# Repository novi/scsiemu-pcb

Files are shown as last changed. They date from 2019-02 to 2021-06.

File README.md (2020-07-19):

# Level Converters for SCSI-bus Emulators

This device enables you to convert logic levels between SCSI-bus and Raspberry-Pi GPIOs.

* Combine with Raspberry Pi Zero
* Supports Target(=e.g. Behaves as SCSI hard-disk) mode
* Supports Initiator, Host(=Dump data from SCSI hard-disk etc...) mode 

NOTE: Some features are depends on your SCSI emulation software.

## Compatible SCSI-bus Emulation Software

* [scsiemu](https://github.com/novi/scsiemu) [WIP]
* [akuker/RASCSI](https://github.com/akuker/RASCSI)

## Gerbers and BOM(Parts List)

* Gerber: `scsiemu-gerber/`
* BOM: `scsiemu-bom.csv`

# Related Projects

* [Tiny SCSI Emulator](https://bitbucket.org/tinyscsi/tinyscsiemulator)
* [LC-SCSI](https://github.com/pgodwin/LC-SCSI)
* [SCSI2SD](http://www.codesrc.com/mediawiki/index.php/SCSI2SD)

# License

[Attribution-ShareAlike 4.0 International (CC BY-SA 4.0)](https://creativecommons.org/licenses/by-sa/4.0/)

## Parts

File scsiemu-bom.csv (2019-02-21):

Ref Name | Qty | Component | Value | Package | Part Number | Part Number (Digi-Key) | Part Number 秋月電子 | Description
RN 5,7,8,10 | 4 |  | 220 | Cat16-8 | CAT16-221J8LF | CAT16-221J8LFCT-ND |  | Resistor
RN 6,9,11 | 3 |  | 330 | Cat16-8 | CAT16-331J8LF | CAT16-331J8LFCT-ND |  | Resistor
RN 1,2,3,4 | 4 |  | 10k | Cat16-8 | CAT16-103J8LF | CAT16-103J8LFCT-ND |  | Resistor
C1,2,3,4 | 4 |  | 0.1u JB | 1206 | C1608JB1H104K |  | P-06166 | Capacitor
C5 | 1 |  | 10u JB | 1206 | GRM319B31C106KE15D |  | P-12730 | Capacitor
F1,2 | 2 |  | 1A | 1206 | 0ZCJ0100FF2E | 507-1806-1-ND |  | Fuse
R1 | 1 | Resistor for LED | 1k | 0603 |  |  |  | Resistor
U1,2,3,4 | 4 |  | 74LS641-1 | SOIC | SN74LS641-1DW | 296-34017-5-ND
FL1,2 | 2 |  | 0.22u |  | NFM21PC224R1C3D | 490-6981-1-ND |  | EMI Filter
LED1 | 1 |  |  | 3mm |  |  |  | LED
J3 | (1) | USB Connector |  |  | ZX62R-B-5P |  | C-05254 | Connector
J2 | (1) | SCSI Connector (DSUB) |  |  | 5787082-5 | A31812-ND |  | Connector
J2 | (1) | SCSI Connector |  |  | 10250-5212PL |  |  | Connector
J1 | 1 | Pin Sockets | 40P |  |  |  | C-00085 | Connector
J4 | (1) | Power Connector | 2P | PH | S2B-PH-K |  | C-12633 | Connector
J5 | (1) | I2C Connector | 3P | PH | S3B-PH-K |  |  | Connector

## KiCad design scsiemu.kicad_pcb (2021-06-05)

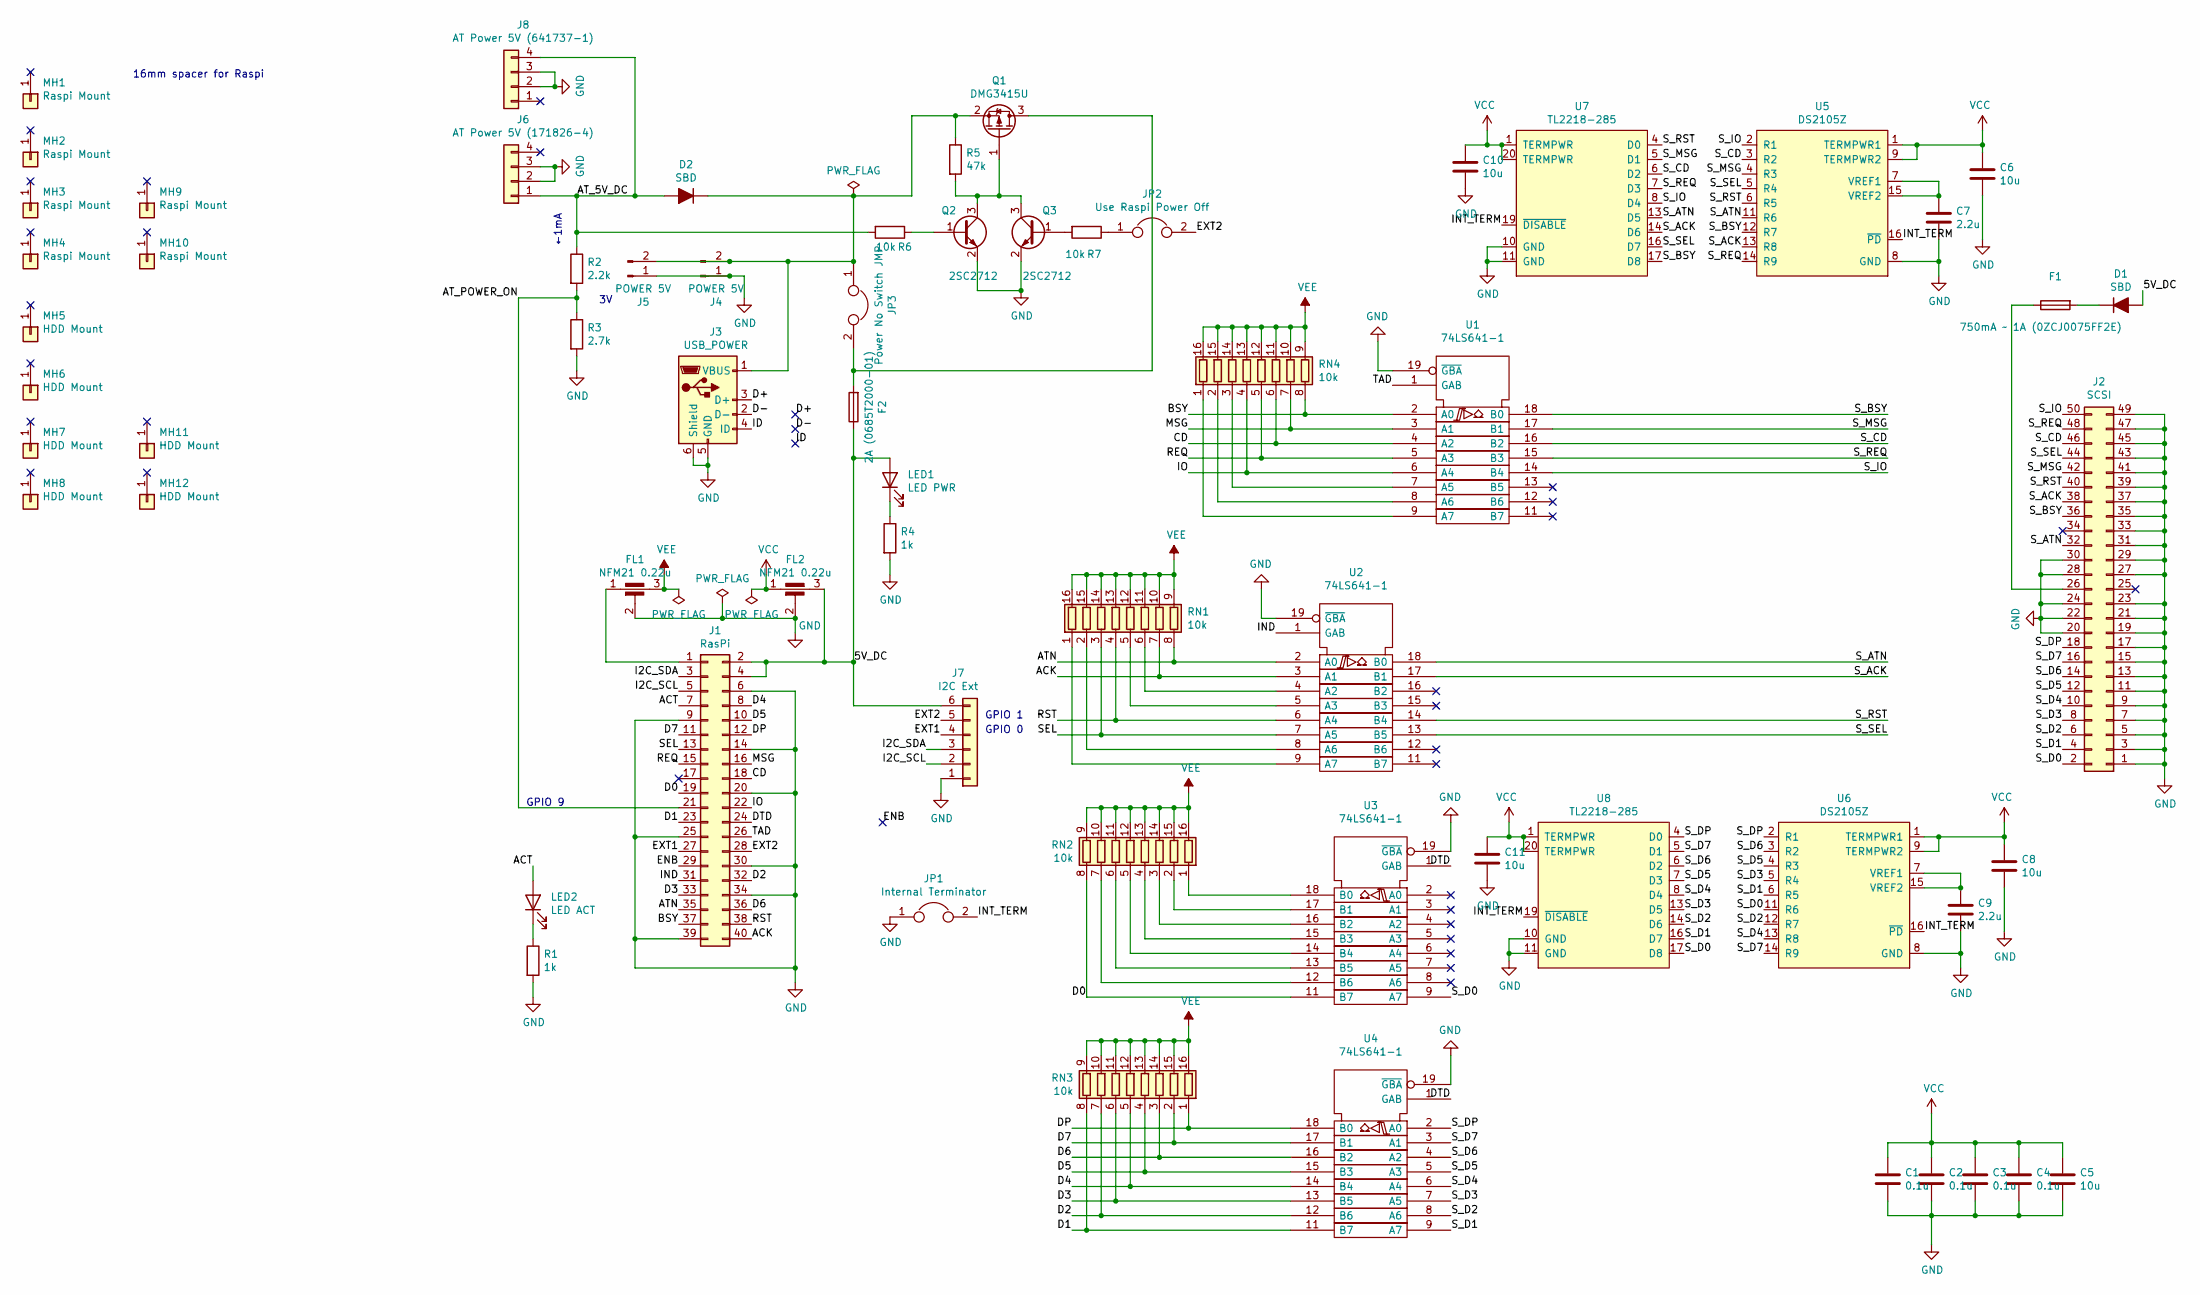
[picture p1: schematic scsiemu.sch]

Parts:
C1, C2, C3, C4: 0.1u; C_0603_1608Metric_Pad1.05x0.95mm_HandSolder
C5, C6, C8, C10, C11: 10u; C_1206_3216Metric_Pad1.42x1.75mm_HandSolder
C7, C9: 2.2u; C_0603_1608Metric_Pad1.05x0.95mm_HandSolder
D1, D2: SBD; D_SOD-123_HandSoldering
F1: 750mA ~~ 1A (0ZCJ0075FF2E); Fuse_1206_3216Metric_Pad1.42x1.75mm_HandSolder
F2: 2A (0685T2000-01); Fuse_1206_3216Metric_Pad1.42x1.75mm_HandSolder
FL1, FL2: NFM21 0.22u; NFM21PC
J1: RasPi; PinSocket_2x20_P2.54mm_Vertical
J2: SCSI; PinHeader_2x25_P2.54mm_Horizontal
J3: USB_POWER; USB_ZX62R-B-5P_HandSoldering
J4, J5: POWER 5V; JST_XH_B2B-XH-A_1x02_P2.50mm_Vertical
J6: AT Power 5V (171826-4); Molex_171826-4
J7: I2C Ext; JST_XH_B6B-XH-A_1x06_P2.50mm_Vertical
J8: AT Power 5V (641737-1); TE_641737-1
JP1: Internal Terminator; PinHeader_1x02_P2.54mm_Vertical
JP2: Use Raspi Power Off; SolderJumper-2_P1.3mm_Open_RoundedPad1.0x1.5mm
JP3: Power No Switch JMP; SolderJumper-2_P1.3mm_Open_RoundedPad1.0x1.5mm
LED1: LED PWR; LED_0603_1608Metric_Pad1.05x0.95mm_HandSolder
LED2: LED ACT; LED_0603_1608Metric_Pad1.05x0.95mm_HandSolder
MH1, MH2, MH3, MH4, MH9, MH10: Raspi Mount; MountingHole_2.2mm_M2
MH5, MH6, MH7, MH8, MH11, MH12: HDD Mount; MountingHole_3.5mm
Q1: DMG3415U; SOT-23_Handsoldering
Q2, Q3: 2SC2712; SOT-23_Handsoldering
R1, R4: 1k; R_0603_1608Metric_Pad1.05x0.95mm_HandSolder
R2: 2.2k; R_0603_1608Metric_Pad1.05x0.95mm_HandSolder
R3: 2.7k; R_0603_1608Metric_Pad1.05x0.95mm_HandSolder
R5: 47k; R_0603_1608Metric_Pad0.98x0.95mm_HandSolder
R6, R7: 10k; R_0603_1608Metric_Pad0.98x0.95mm_HandSolder
RN1, RN2, RN3, RN4: 10k; R_Cat16-8
U1, U2, U3, U4: 74LS641-1; SO-20_12.8x7.5mm_P1.27mm
U5, U6: DS2105Z; SOIC-16_3.9x9.9mm_P1.27mm
U7, U8: TL2218-285; TSSOP-20_4.4x6.5mm_P0.65mm

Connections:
/5V_DC: D1.2 (A), F2.1, FL2.3, J1.2, J1.4, J7.6, LED1.2 (A)
/ACK: J1.40, RN1.7 (R7.1), U2.3 (A1)
/ACT: J1.7, LED2.2 (A)
/ATN: J1.35, RN1.8 (R8.1), U2.2 (A0)
/AT_5V_DC: D2.2 (A), J6.1, J8.4, R2.1, R6.2
/AT_POWER_ON: J1.21, R2.2, R3.1
/BSY: J1.37, RN4.8 (R8.1), U1.2 (A0)
/CD: J1.18, RN4.6 (R6.1), U1.4 (A2)
/D0: J1.19, RN2.8 (R8.1), U3.11 (B7)
/D1: J1.23, RN3.8 (R8.1), U4.11 (B7)
/D2: J1.32, RN3.7 (R7.1), U4.12 (B6)
/D3: J1.33, RN3.6 (R6.1), U4.13 (B5)
/D4: J1.8, RN3.5 (R5.1), U4.14 (B4)
/D5: J1.10, RN3.4 (R4.1), U4.15 (B3)
/D6: J1.36, RN3.3 (R3.1), U4.16 (B2)
/D7: J1.11, RN3.2 (R2.1), U4.17 (B1)
/D+: J3.3 (D+)
/D-: J3.2 (D-)
/DP: J1.12, RN3.1 (R1.1), U4.18 (B0)
/DTD: J1.24, U3.1 (GAB), U4.1 (GAB)
/ENB: J1.29
/EXT1: J1.27, J7.4
/EXT2: J1.28, J7.5, JP2.2
/I2C_SCL: J1.5, J7.2
/I2C_SDA: J1.3, J7.3
/ID: J3.4 (ID)
/IND: J1.31, U2.1 (GAB)
/INT_TERM: JP1.2, U5.16 (~PD), U6.16 (~PD), U7.19 (~DISABLE), U8.19 (~DISABLE)
/IO: J1.22, RN4.4 (R4.1), U1.6 (A4)
/MSG: J1.16, RN4.7 (R7.1), U1.3 (A1)
/REQ: J1.15, RN4.5 (R5.1), U1.5 (A3)
/RST: J1.38, RN1.4 (R4.1), U2.6 (A4)
/SEL: J1.13, RN1.3 (R3.1), U2.7 (A5)
/S_ACK: J2.38, U2.17 (B1), U5.13 (R8), U7.14 (D6)
/S_ATN: J2.32, U2.18 (B0), U5.11 (R6), U7.13 (D5)
/S_BSY: J2.36, U1.18 (B0), U5.12 (R7), U7.17 (D8)
/S_CD: J2.46, U1.16 (B2), U5.3 (R2), U7.6 (D2)
/S_D0: J2.2, U3.9 (A7), U6.11 (R6), U8.17 (D8)
/S_D1: J2.4, U4.9 (A7), U6.6 (R5), U8.16 (D7)
/S_D2: J2.6, U4.8 (A6), U6.12 (R7), U8.14 (D6)
/S_D3: J2.8, U4.7 (A5), U6.5 (R4), U8.13 (D5)
/S_D4: J2.10, U4.6 (A4), U6.13 (R8), U8.8 (D4)
/S_D5: J2.12, U4.5 (A3), U6.4 (R3), U8.7 (D3)
/S_D6: J2.14, U4.4 (A2), U6.3 (R2), U8.6 (D2)
/S_D7: J2.16, U4.3 (A1), U6.14 (R9), U8.5 (D1)
/S_DP: J2.18, U4.2 (A0), U6.2 (R1), U8.4 (D0)
/S_IO: J2.50, U1.14 (B4), U5.2 (R1), U7.8 (D4)
/S_MSG: J2.42, U1.17 (B1), U5.4 (R3), U7.5 (D1)
/S_REQ: J2.48, U1.15 (B3), U5.14 (R9), U7.7 (D3)
/S_RST: J2.40, U2.14 (B4), U5.6 (R5), U7.4 (D0)
/S_SEL: J2.44, U2.13 (B5), U5.5 (R4), U7.16 (D7)
/TAD: J1.26, U1.1 (GAB)
GND: C1.2, C2.2, C3.2, C4.2, C5.2, C6.2, C7.2, C8.2, C9.2, C10.2, C11.2, FL1.2, FL2.2, J1.6, J1.9, J1.14, J1.20, J1.25, J1.30, J1.34, J1.39, J2.1, J2.3, J2.5, J2.7, J2.9, J2.11, J2.13, J2.15, J2.17, J2.19, J2.20, J2.21, J2.22, J2.23, J2.24, J2.27, J2.28, J2.29, J2.30, J2.31, J2.33, J2.35, J2.37, J2.39, J2.41, J2.43, J2.45, J2.47, J2.49, J3.5 (GND), J3.6 (Shield), J4.1, J5.1, J6.2, J6.3, J7.1, J8.2, J8.3, JP1.1, Q2.2 (E), Q3.2 (E), R1.2, R3.2, R4.2, U1.10 (GND), U1.19 (~GBA), U2.10 (GND), U2.19 (~GBA), U3.10 (GND), U3.19 (~GBA), U4.10 (GND), U4.19 (~GBA), U5.8 (GND), U6.8 (GND), U7.10 (GND), U7.11 (GND), U8.10 (GND), U8.11 (GND)
unnamed: C7.1, U5.7 (VREF1), U5.15 (VREF2)
unnamed: C9.1, U6.7 (VREF1), U6.15 (VREF2)
unnamed: D1.1 (K), F1.2
unnamed: D2.1 (K), J3.1 (VBUS), J4.2, J5.2, JP3.1, Q1.2 (S), R5.1
unnamed: F1.1, J2.26
unnamed: F2.2, JP3.2, Q1.3 (D)
unnamed: FL1.1, J1.1
unnamed: JP2.1, R7.1
unnamed: LED1.1 (K), R4.1
unnamed: LED2.1 (K), R1.1
unnamed: Q1.1 (G), Q2.3 (C), Q3.3 (C), R5.2
unnamed: Q2.1 (B), R6.1
unnamed: Q3.1 (B), R7.2
unnamed: RN1.1 (R1.1), U2.9 (A7)
unnamed: RN1.2 (R2.1), U2.8 (A6)
unnamed: RN1.5 (R5.1), U2.5 (A3)
unnamed: RN1.6 (R6.1), U2.4 (A2)
unnamed: RN2.1 (R1.1), U3.18 (B0)
unnamed: RN2.2 (R2.1), U3.17 (B1)
unnamed: RN2.3 (R3.1), U3.16 (B2)
unnamed: RN2.4 (R4.1), U3.15 (B3)
unnamed: RN2.5 (R5.1), U3.14 (B4)
unnamed: RN2.6 (R6.1), U3.13 (B5)
unnamed: RN2.7 (R7.1), U3.12 (B6)
unnamed: RN4.1 (R1.1), U1.9 (A7)
unnamed: RN4.2 (R2.1), U1.8 (A6)
unnamed: RN4.3 (R3.1), U1.7 (A5)
VCC: C1.1, C2.1, C3.1, C4.1, C5.1, C6.1, C8.1, C10.1, C11.1, FL2.1, U1.20 (VCC), U2.20 (VCC), U3.20 (VCC), U4.20 (VCC), U5.1 (TERMPWR1), U5.9 (TERMPWR2), U6.1 (TERMPWR1), U6.9 (TERMPWR2), U7.1 (TERMPWR), U7.20 (TERMPWR), U8.1 (TERMPWR), U8.20 (TERMPWR)
VEE: FL1.3, RN1.9 (R8.2), RN1.10 (R7.2), RN1.11 (R6.2), RN1.12 (R5.2), RN1.13 (R4.2), RN1.14 (R3.2), RN1.15 (R2.2), RN1.16 (R1.2), RN2.9 (R8.2), RN2.10 (R7.2), RN2.11 (R6.2), RN2.12 (R5.2), RN2.13 (R4.2), RN2.14 (R3.2), RN2.15 (R2.2), RN2.16 (R1.2), RN3.9 (R8.2), RN3.10 (R7.2), RN3.11 (R6.2), RN3.12 (R5.2), RN3.13 (R4.2), RN3.14 (R3.2), RN3.15 (R2.2), RN3.16 (R1.2), RN4.9 (R8.2), RN4.10 (R7.2), RN4.11 (R6.2), RN4.12 (R5.2), RN4.13 (R4.2), RN4.14 (R3.2), RN4.15 (R2.2), RN4.16 (R1.2)

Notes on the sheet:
←1mA
GPIO 0
GPIO 1
16mm spacer for Raspi
GPIO 9

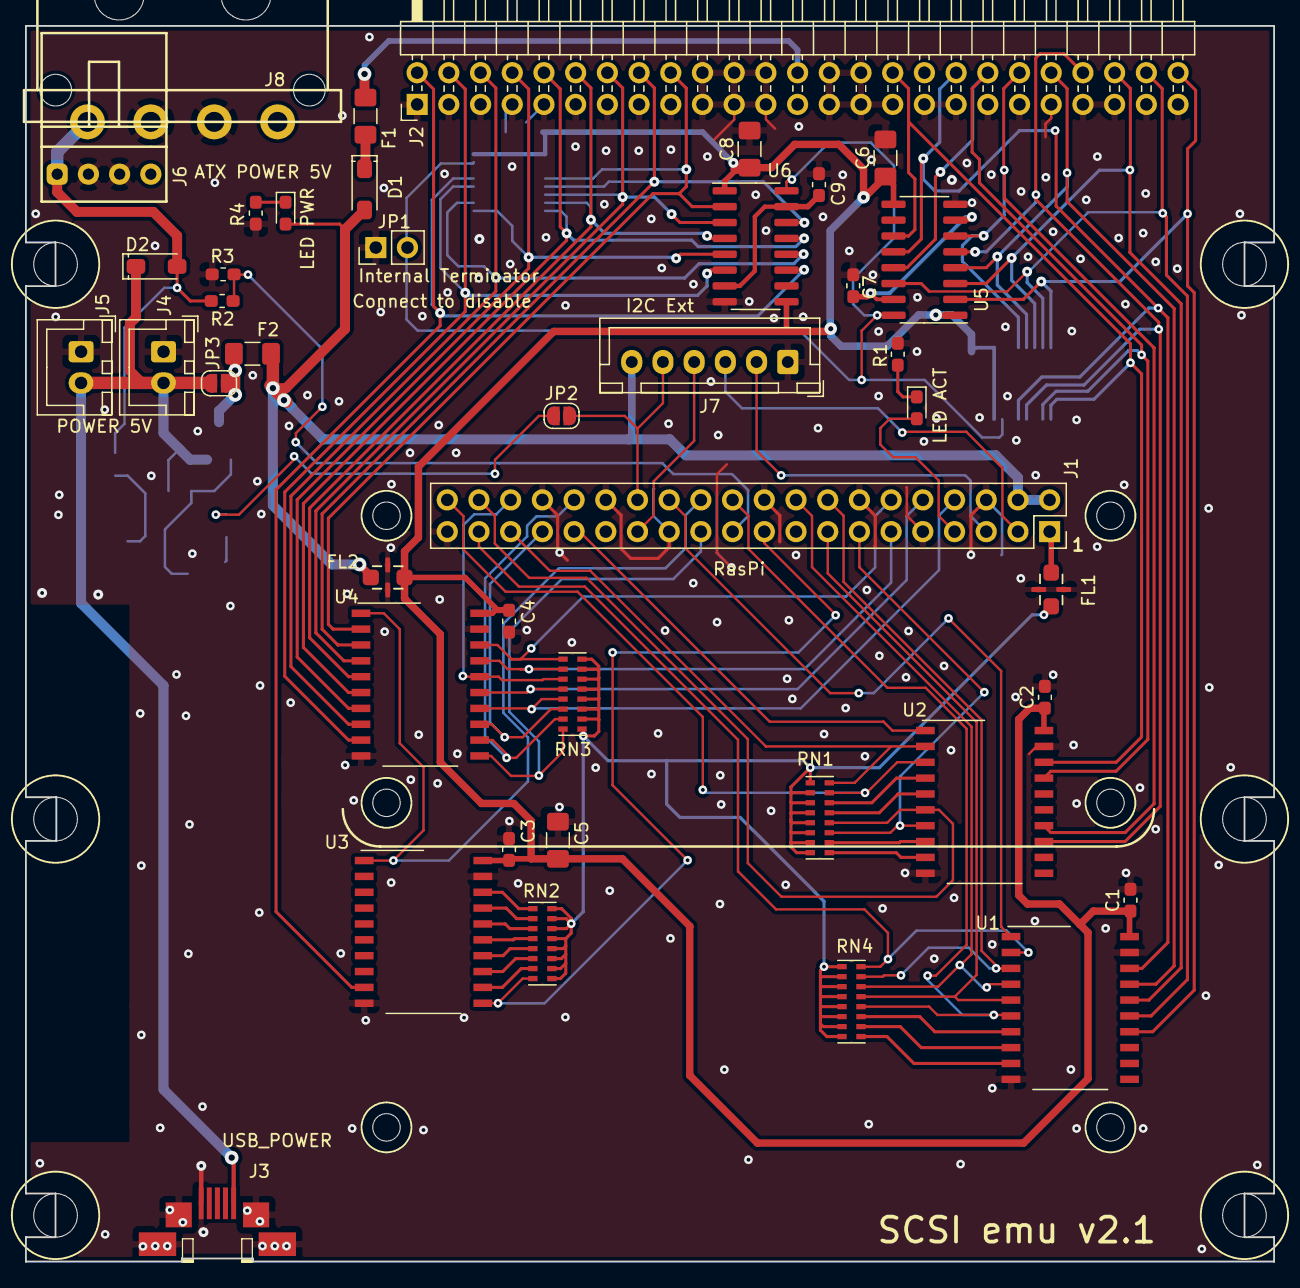
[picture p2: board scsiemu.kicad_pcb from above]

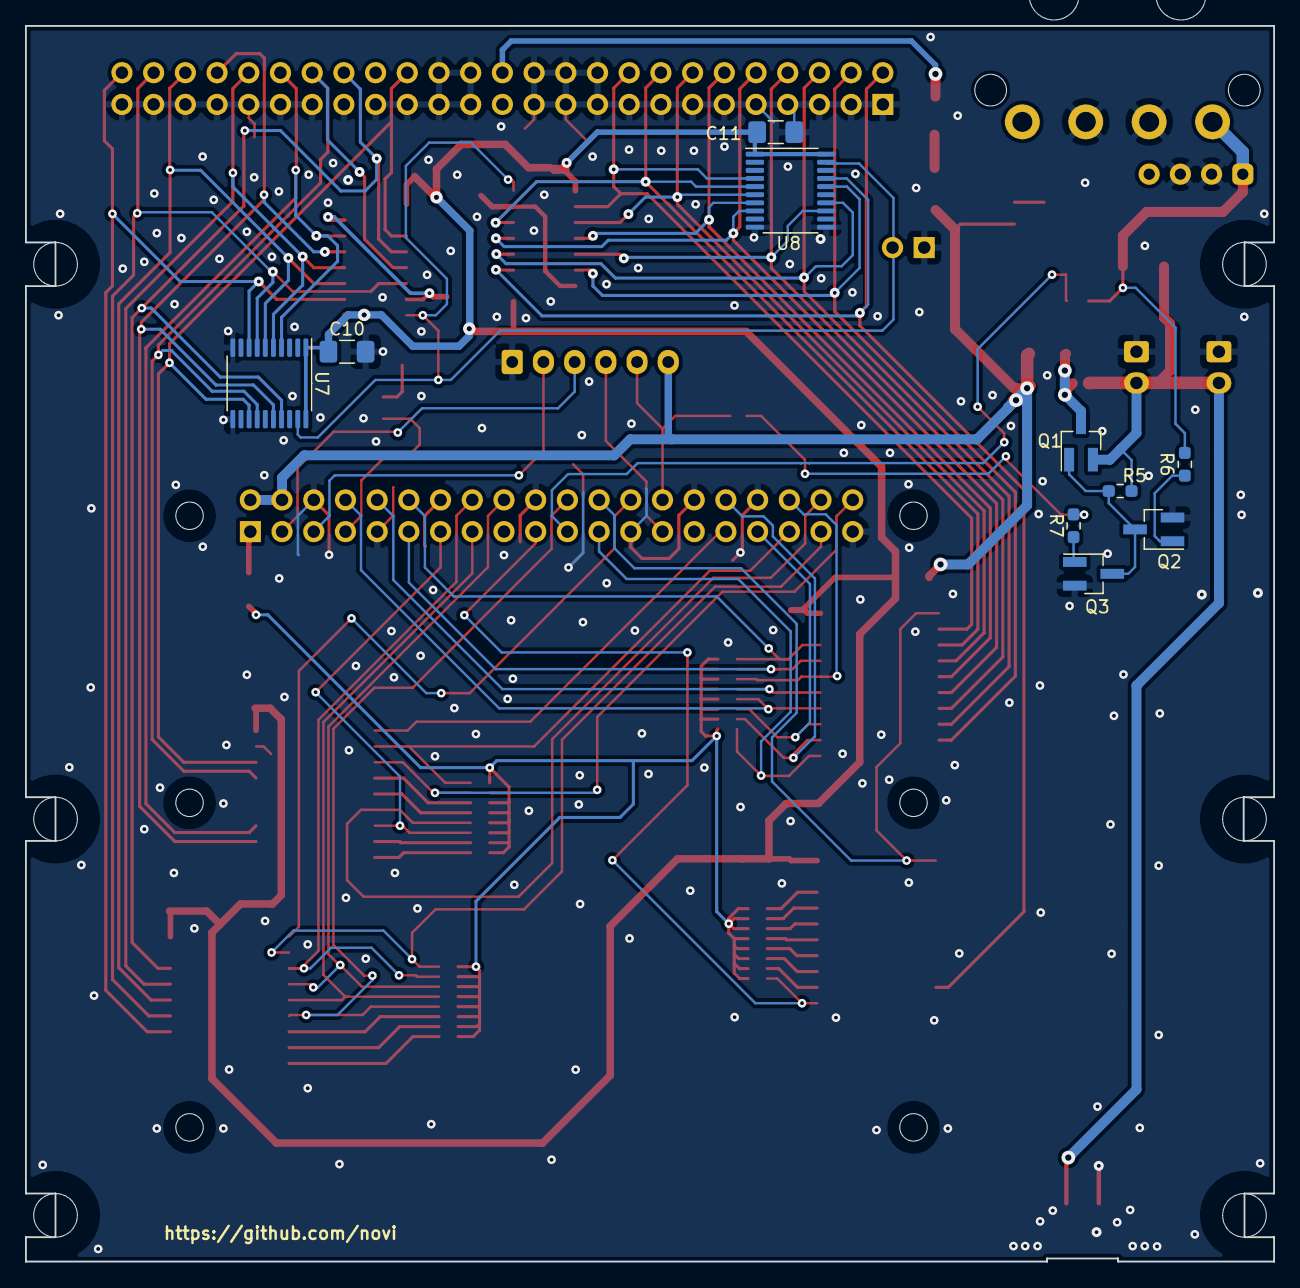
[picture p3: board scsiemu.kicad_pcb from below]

Board: 2 copper layers, 100.0 x 99.0 mm, 64 parts (10 on the bottom side), 78 nets.

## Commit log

2019-02-21 add KiCad projects
    [scsiemu-bom.csv, scsiemu.kicad_pcb, scsiemu.sch]
2020-05-16 add gerber files
    [scsiemu-B_Cu.gbl, scsiemu-B_Mask.gbs, scsiemu-B_Paste.gbp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]
2020-09-13 Internal 50pin version (#1)
    [scsiemu-B_Cu.gbl, scsiemu-B_Mask.gbs, scsiemu-B_Paste.gbp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]
2020-09-26 termination on/off jumper fix GND plane
    [scsiemu.kicad_pcb, scsiemu.sch]
2021-04-17 minor update
    [scsiemu.kicad_pcb, scsiemu.sch]
2021-04-18 add auto power off
    [scsiemu.kicad_pcb, scsiemu.sch]
2021-04-18 update track
    [scsiemu.kicad_pcb]
2021-04-18 plot gerber
    [scsiemu-B_Cu.gbl, scsiemu-B_Mask.gbs, scsiemu-B_Paste.gbp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]
2021-06-05 update keepout area
    [scsiemu.kicad_pcb]
